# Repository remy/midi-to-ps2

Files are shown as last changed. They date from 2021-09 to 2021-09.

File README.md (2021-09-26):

# MIDI to Keyboard over PS/2 (and USB)

This project was originally designed for [NextDAW](http://nextdaw.biasillo.com/) to let you control the software using a real MIDI keyboard.

The device can connect over PS/2 interface but also USB and announces itself as a keyboard - which means you can use this on a device like a MiSTer or even a PC.

The code should be relatively straight forward to update for your own means if you desire a different mapping.

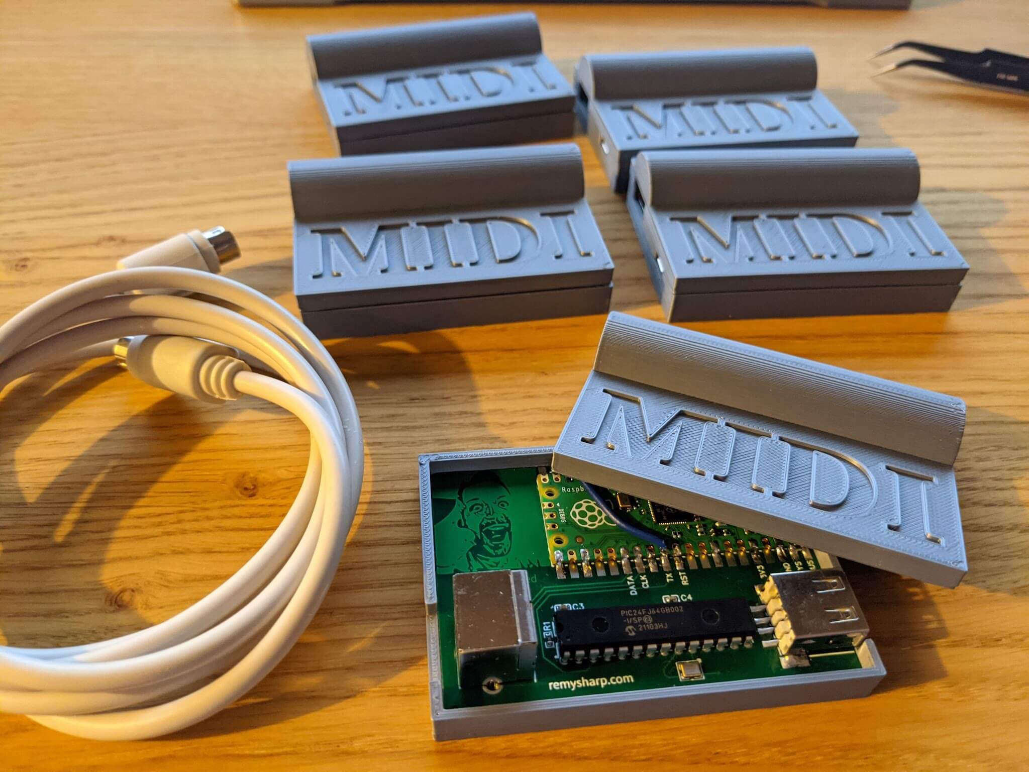
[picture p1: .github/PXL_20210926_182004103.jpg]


## Materials

To build this project, the raw components you'll need (and approximate price at time of publishing) are as follow.

None of the links are affiliates and just the suggestions that I've used.

- Raspberry Pico - [£3.60 / Pimoroni](https://shop.pimoroni.com/products/raspberry-pi-pico?variant=32402092294227)
- USB host controller IC - [£5.76 / Hobby Tronics](https://www.hobbytronics.co.uk/usb-host/usb-host-dip)
- USB type A female connector - [£0.72 / Hobby Tronics](https://www.hobbytronics.co.uk/usb-type-a-socket)
- PS/2 6 Pin mini DIN female (if required) - [can be around £0.65, but here's an example on Amazon](https://www.amazon.co.uk/sourcingmap%C2%AE-Shielded-Female-Board-Connector-Silver/dp/B007PPHYFM)
- 16Mhz crystal oscillator + 2x18pF capacitors - [£0.54 / HobbyTronics](https://www.hobbytronics.co.uk/xtal-caps)
- 100nF capacitor
- 10uF capacitor
- 10K resistor

Once built, use the [latest release](https://github.com/remy/midi-to-ps2/releases/latest) and upload the firmware.

## Uploading firmware

With the Pico disconnected, hold down the white boot button, then attach to a PC using the USB port.

The Pico will become available as a mounted drive. Drag and drop the latest release on to the drive. It will automatically disconnect the Pico and the new firmware will be flashed and available.

## MIDI configuration

NextDAW supports 29 keys which are mapped across two (plus some) octaves from C2 to (nearly) C5 - from C2 to F4.

Currently on a single knob has been implemented with the specific settings of: CC 73, LO 0, HI 127, relative. This will move the play head.

More control can be added either as NextDAW is updated or as requested.

## TODO

- [ ] How to change key mappings
- [ ] Explain source code
- [ ] Notes on PCB and STL files

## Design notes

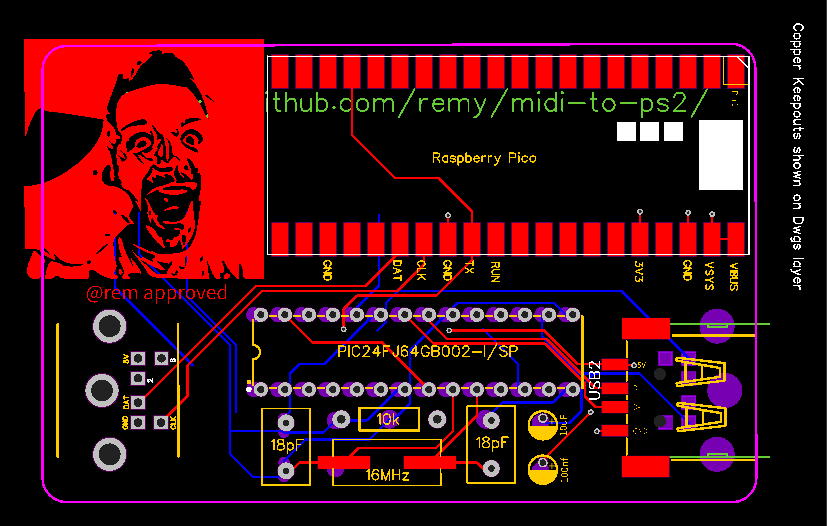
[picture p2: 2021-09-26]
pcb/PCB_PCB_midi to ps_2 - 2.1 - THT 2021-09-21.png

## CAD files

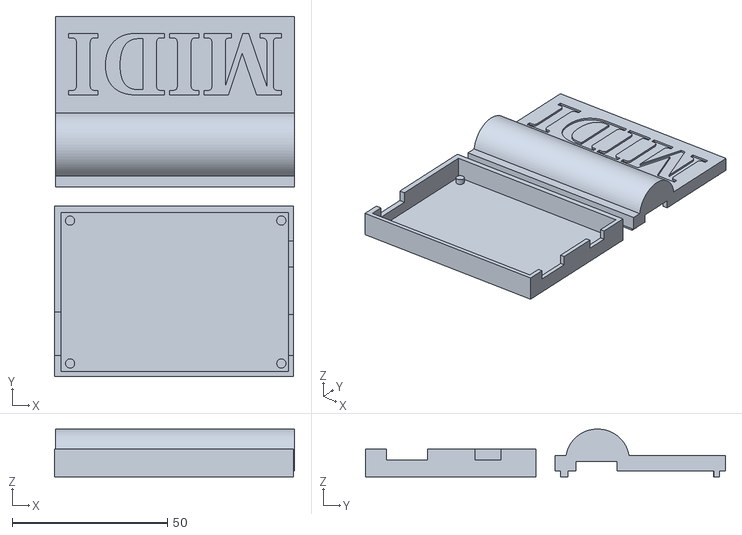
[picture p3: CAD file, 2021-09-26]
3d-enclosure/ps2 to midi house-14.25.stl
77.2 x 116.0 x 15.4

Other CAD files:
3d-enclosure/ps2 to midi house-purple.stl

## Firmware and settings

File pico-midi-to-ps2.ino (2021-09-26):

//#include <Adafruit_TinyUSB.h>
#include <Keyboard.h>

#include "ps2dev.h"
#include "scancodes.h" // inludes the defines for SCANCODE_*

#define midiIn Serial1

PS2dev keyboard(21, 20); //clock, data

char buff[20];

// notes are from 0 to 28 (29 keys) starting at C2 (0 index shifted to 48)
// A good reference is this pdf: https://www.hobbytronics.co.uk/datasheets/9_MIDI_code.pdf
const uint8_t notesToKey[] = {
    SCANCODE_Z, SCANCODE_S, SCANCODE_X, SCANCODE_D, SCANCODE_C, SCANCODE_V, SCANCODE_G, SCANCODE_B, SCANCODE_H, SCANCODE_N, SCANCODE_J, SCANCODE_M,
    SCANCODE_Q, SCANCODE_2, SCANCODE_W, SCANCODE_3, SCANCODE_E, SCANCODE_R, SCANCODE_5, SCANCODE_T, SCANCODE_6, SCANCODE_Y, SCANCODE_7, SCANCODE_U, SCANCODE_I, SCANCODE_9, SCANCODE_O, SCANCODE_0, SCANCODE_P};

const uint8_t notesToChar[] = {
    'z', 's', 'x', 'd', 'c', 'v', 'g', 'b', 'h', 'n', 'j', 'm',
    'q', '2', 'w', '3', 'e', 'r', '5', 't', '6', 'y', '7', 'u', 'i', '9', 'o', '0', 'p'};

uint8_t getCodeForNote(uint8_t note)
{
  return notesToKey[note - 0x30];
}

uint8_t getCharForNote(uint8_t note)
{
  return notesToChar[note - 0x30];
}

void setup()
{
  midiIn.setRX(13);
  midiIn.setTX(12);

  pinMode(LED_BUILTIN, OUTPUT);
  keyboard.init();

  Serial.begin(115200);
  Keyboard.begin();

  midiIn.begin(31250);
  digitalWrite(LED_BUILTIN, HIGH);
  delay(200);
  digitalWrite(LED_BUILTIN, LOW);
  delay(200);
  digitalWrite(LED_BUILTIN, HIGH);
  delay(200);
  digitalWrite(LED_BUILTIN, LOW);
  delay(200);
  digitalWrite(LED_BUILTIN, HIGH);
  delay(200);
  digitalWrite(LED_BUILTIN, LOW);
  delay(200);
  digitalWrite(LED_BUILTIN, HIGH);
  delay(200);
  digitalWrite(LED_BUILTIN, LOW);
}

uint8_t next()
{
  while (!midiIn.available())
  {
  }
  return (uint8_t)midiIn.read();
}

#define MIDI_NOTE_OFF 0x8
#define MIDI_NOTE_ON 0x9
#define MIDI_CONTROL 0xb
#define MIDI_PITCH 0xe
#define MIDI_SYSEX 0xf

void loop()
{
  uint8_t status = 0;
  uint8_t nibble = 0;
  uint8_t data0 = 0;
  uint8_t data1 = 0;
  uint8_t data2 = 0;

  if (midiIn.available())
  {
    data0 = next();

    if (data0 & 0x80)
    {
      status = data0;
      data1 = next();
      data2 = next();
    }
    else
    {
      data1 = data0;
      data2 = next();
    }

    nibble = (status >> 4);

    //    sprintf (buff, "(%1x) %2x %2x %2x", nibble, status, data1, data2);
    //    Serial.println(buff);
    int code = getCodeForNote(data1);
    int chr = getCharForNote(data1);

    if (nibble == MIDI_NOTE_OFF)
    {
      // note off
      keyboard.write(0xf0);
      keyboard.write(code);
      Keyboard.release(chr);
      digitalWrite(LED_BUILTIN, LOW);
    }
    else if (nibble == MIDI_NOTE_ON)
    {
      digitalWrite(LED_BUILTIN, HIGH);

      if (data2 == 0)
      {
        // velocity off = note off
        keyboard.write(0xf0);
        Keyboard.release(chr);
        digitalWrite(LED_BUILTIN, LOW);
      }

      // note on
      keyboard.write(code);
      Keyboard.press(chr);
    }
    else if (nibble == MIDI_CONTROL)
    {
      // control
      if (data1 == 0x4a)
      {
        digitalWrite(LED_BUILTIN, HIGH);
        // shift down
        keyboard.write(SCANCODE_CONTROLLEFT);
        Keyboard.press(KEY_LEFT_CTRL);
        // send N/M
        int code = data2 == 1 ? SCANCODE_M : SCANCODE_N;
        int chr = data2 == 1 ? 'm' : 'n';
        keyboard.write(code);
        Keyboard.press(chr);
        // send keyup
        keyboard.write(0xf0);
        keyboard.write(code);
        // shift up
        keyboard.write(0xf0);
        keyboard.write(SCANCODE_CONTROLLEFT);
        digitalWrite(LED_BUILTIN, LOW);
        Keyboard.releaseAll();
      }
    }
    else if (nibble == MIDI_PITCH)
    {
      // pitch
    }
    else if (nibble == MIDI_SYSEX)
    {
      // system message - we just slurp
      //      while (next() != 0xF7) {}
    }
  }
}

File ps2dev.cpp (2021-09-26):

/*
 * ps2dev.cpp - an interface library for ps2 host.
 * limitations:
 *      we do not handle parity errors.
 *      The timing constants are hard coded from the spec. Data rate is
 *         not impressive.
 *      probably lots of room for optimization.
 *
 * Modified for Pico by @rem - 2021-08-27
 */

#include <stdio.h>
#include "pico/stdlib.h"
#include "ps2dev.h"
#include "Arduino.h"

#define HIGH 1
#define LOW 0

//Enable serial debug mode?
#define _PS2DBG 1

//since for the device side we are going to be in charge of the clock,
//the two defines below are how long each _phase_ of the clock cycle is
#define CLKFULL 40
// we make changes in the middle of a phase, this how long from the
// start of phase to the when we drive the data line
#define CLKHALF 20

// Delay between bytes
// I've found i need at least 400us to get this working at all,
// but even more is needed for reliability, so i've put 1000us
#define BYTEWAIT 1000

// Timeout if computer not sending for 30ms
#define TIMEOUT 30

/*
 * the clock and data pins can be wired directly to the clk and data pins
 * of the PS2 connector.  No external parts are needed.
 */
PS2dev::PS2dev(int clk, int data)
{
  _ps2clk = clk;
  _ps2data = data;
}

void PS2dev::init()
{
  gpio_init(_ps2clk);
  gpio_init(_ps2data);

  gpio_set_dir(_ps2clk, GPIO_OUT);
  gpio_set_dir(_ps2data, GPIO_OUT);

  gohi(_ps2clk);
  gohi(_ps2data);
}

/*
 * according to some code I saw, these functions will
 * correctly set the clock and data pins for
 * various conditions.  It's done this way so you don't need
 * pullup resistors.
 */
void PS2dev::gohi(int pin)
{
  gpio_set_function(pin, GPIO_FUNC_SIO);
//  gpio_set_dir(pin, GPIO_OUT);
  gpio_put(pin, 1);
  //  pinMode(pin, INPUT);
  //  digitalWrite(pin, HIGH);
}

void PS2dev::golo(int pin)
{
  gpio_set_function(pin, GPIO_FUNC_SIO);
  gpio_put(pin, 0);
//  gpio_set_dir(pin, GPIO_OUT);
  //  digitalWrite(pin, LOW);
  //  pinMode(pin, OUTPUT);
}

int PS2dev::write(unsigned char data)
{
  sleep_us(BYTEWAIT);

  unsigned char i;
  unsigned char parity = 1;

#ifdef _PS2DBG
  printf("sending ");
  printf("%2x\n", data);
#endif

  Serial.print("sending ");
  Serial.println(data, HEX);

  if (gpio_get(_ps2clk) == LOW)
  {
    return -1;
  }

  if (gpio_get(_ps2data) == LOW)
  {
    return -2;
  }

  golo(_ps2data);
  sleep_us(CLKHALF);
  // device sends on falling clock
  golo(_ps2clk); // start bit
  sleep_us(CLKFULL);
  gohi(_ps2clk);
  sleep_us(CLKHALF);

  for (i = 0; i < 8; i++)
  {
    if (data & 0x01)
    {
      gohi(_ps2data);
    }
    else
    {
      golo(_ps2data);
    }
    sleep_us(CLKHALF);
    golo(_ps2clk);
    sleep_us(CLKFULL);
    gohi(_ps2clk);
    sleep_us(CLKHALF);

    parity = parity ^ (data & 0x01);
    data = data >> 1;
  }
  // parity bit
  if (parity)
  {
    gohi(_ps2data);
  }
  else
  {
    golo(_ps2data);
  }
  sleep_us(CLKHALF);
  golo(_ps2clk);
  sleep_us(CLKFULL);
  gohi(_ps2clk);
  sleep_us(CLKHALF);

  // stop bit
  gohi(_ps2data);
  sleep_us(CLKHALF);
  golo(_ps2clk);
  sleep_us(CLKFULL);
  gohi(_ps2clk);
  sleep_us(CLKHALF);

  sleep_us(BYTEWAIT);

#ifdef _PS2DBG
  printf("sent ");
  printf("%2x\n", data);
#endif

  return 0;
}

int PS2dev::available()
{
  //sleep_us(BYTEWAIT);
  return ((gpio_get(_ps2data) == LOW) || (gpio_get(_ps2clk) == LOW));
}

int PS2dev::read(unsigned char *value)
{
  unsigned int data = 0x00;
  unsigned int bit = 0x01;

  unsigned char calculated_parity = 1;
  unsigned char received_parity = 0;

  //wait for data line to go low and clock line to go high (or timeout)
  unsigned long waiting_since = to_ms_since_boot(get_absolute_time());
  while ((gpio_get(_ps2data) != LOW) || (gpio_get(_ps2clk) != HIGH))
  {
    if ((to_ms_since_boot(get_absolute_time()) - waiting_since) > TIMEOUT)
      return -1;
  }

  sleep_us(CLKHALF);
  golo(_ps2clk);
  sleep_us(CLKFULL);
  gohi(_ps2clk);
  sleep_us(CLKHALF);

  while (bit < 0x0100)
  {
    if (gpio_get(_ps2data) == HIGH)
    {
      data = data | bit;
      calculated_parity = calculated_parity ^ 1;
    }
    else
    {
      calculated_parity = calculated_parity ^ 0;
    }

    bit = bit << 1;

    sleep_us(CLKHALF);
    golo(_ps2clk);
    sleep_us(CLKFULL);
    gohi(_ps2clk);
    sleep_us(CLKHALF);
  }
  // we do the delay at the end of the loop, so at this point we have
  // already done the delay for the parity bit

  // parity bit
  if (gpio_get(_ps2data) == HIGH)
  {
    received_parity = 1;
  }

  // stop bit
  sleep_us(CLKHALF);
  golo(_ps2clk);
  sleep_us(CLKFULL);
  gohi(_ps2clk);
  sleep_us(CLKHALF);

  sleep_us(CLKHALF);
  golo(_ps2data);
  golo(_ps2clk);
  sleep_us(CLKFULL);
  gohi(_ps2clk);
  sleep_us(CLKHALF);
  gohi(_ps2data);

  *value = data & 0x00FF;

  if (received_parity == calculated_parity)
  {
    return 0;
  }
  else
  {
    return -2;
  }
}

void PS2dev::keyboard_init()
{
  while (write(0xAA) != 0)
    ;
  sleep_ms(10);
  return;
}

void PS2dev::ack()
{
  while (write(0xFA))
    ;
  return;
}

int PS2dev::keyboard_reply(unsigned char cmd, unsigned char *leds)
{
  unsigned char val;
  unsigned char enabled;
  switch (cmd)
  {
  case 0xFF: //reset
    ack();
    //the while loop lets us wait for the host to be ready
    while (write(0xAA) != 0)
      ;
    break;
  case 0xFE: //resend
    ack();
    break;
  case 0xF6: //set defaults
    //enter stream mode
    ack();
    break;
  case 0xF5: //disable data reporting
    //FM
    enabled = 0;
    ack();
    break;
  case 0xF4: //enable data reporting
    //FM
    enabled = 1;
    ack();
    break;
  case 0xF3: //set typematic rate
    ack();
    if (!read(&val))
      ack(); //do nothing with the rate
    break;
  case 0xF2: //get device id
    ack();
    write(0xAB);
    write(0x83);
    break;
  case 0xF0: //set scan code set
    ack();
    if (!read(&val))
      ack(); //do nothing with the rate
    break;
  case 0xEE: //echo
    //ack();
    write(0xEE);
    break;
  case 0xED: //set/reset LEDs
    ack();
    if (!read(leds))
      ack(); //do nothing with the rate
#ifdef _PS2DBG
    printf("LEDs: ");
    printf("%2x\n", *leds);
    //digitalWrite(LED_BUILTIN, *leds);
#endif
    return 1;
    break;
  }
  return 0;
}

int PS2dev::keyboard_handle(unsigned char *leds)
{
  unsigned char c; //char stores data recieved from computer for KBD
  if (available())
  {
    if (!read(&c))
      return keyboard_reply(c, leds);
  }
  return 0;
}

// Presses then releases one of the non-special characters
int PS2dev::keyboard_mkbrk(unsigned char code)
{
  write(code);
  write(0xF0);
  write(code);
  return 0;
}

// Presses one of the non-special characters
int PS2dev::keyboard_press(unsigned char code)
{
  return write(code);
}

// Releases one of the non-special characters
int PS2dev::keyboard_release(unsigned char code)
{
  write(0xf0);
  write(code);

  return 0;
}

// Presses one of the special characters
int PS2dev::keyboard_press_special(unsigned char code)
{
  write(0xe0);
  write(code);

  return 0;
}
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

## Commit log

2021-09-03 add arduino build support
2021-09-26 adding physical assets
    [ps2 to midi house-14.25.stl, ps2 to midi house-purple.stl]
